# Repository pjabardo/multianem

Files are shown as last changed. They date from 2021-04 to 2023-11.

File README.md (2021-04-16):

# multianem - Multiple channel thermistor based CTA anemometer

This projecto has as its objective implement low cost multiple channel thermistor based constant temperature anemometer systems. This projecto includes the KICAD projects for the sensors and data acquisition system.

The main objective is to design a robust, cheap and easily sourced system. By easily sourced system, I mean that the components should be readily available in Brazil.

The project has different parts:

 * `multiname`: Basic board with 8 sensors.
 * `esp32-daq-board`: Data acquisition system for 32 channels
 * `multianem-box`: 3D printed/CNC casing for the system.
 * `multianemdaq`: embedded data acquisition software for the ESP32
 * Other software: data acquisition for Julia, R and Python (nothing to see yet...)

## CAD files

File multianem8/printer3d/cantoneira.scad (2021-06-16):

$fa = 1;
$fs = 0.4;

err = 0.0001;
esp = 3.0;
R = 1.5;

D = 9.5;

e = (D - 8.3)/2;
L = 190.0;
W = 190.0;
H = 80;
L1 = 12.0;



union(){
translate([-5, 0, 0])
rotate([0, -90, 0])
difference(){
union(){
    cube([esp, H, esp+L1]);
    cube([esp+L1, esp, esp+L1]);
    cube([esp+L1, H, esp]);
    
    translate([0, H-esp, 0])
    cube([esp+L1, esp, esp+L1]);
    
}

translate([esp+L1/2, esp+L1/2, -10])    
cylinder(h=20, r=1.5);

translate([esp+L1/2, H-esp-L1/2, -10])    
cylinder(h=20, r=1.5);

translate([esp+L1/2, -10, esp+L1/2])    
rotate([-90,0,0])
cylinder(h=20, r=1.5);

translate([esp+L1/2, H-10, esp+L1/2])    
rotate([-90,0,0])
cylinder(h=20, r=1.5);

translate([-10, esp+L1/2,  esp+L1/2])    
rotate([0, 90,0])
cylinder(h=20, r=1.5);

translate([-10, H-esp-L1/2,  esp+L1/2])    
rotate([0, 90,0])
cylinder(h=20, r=1.5);

}




difference(){
union(){
    cube([esp, H, esp+L1]);
    cube([esp+L1, esp, esp+L1]);
    cube([esp+L1, H, esp]);
    
    translate([0, H-esp, 0])
    cube([esp+L1, esp, esp+L1]);
    
}

translate([esp+L1/2, esp+L1/2, -10])    
cylinder(h=20, r=1.5);

translate([esp+L1/2, H-esp-L1/2, -10])    
cylinder(h=20, r=1.5);

translate([esp+L1/2, -10, esp+L1/2])    
rotate([-90,0,0])
cylinder(h=20, r=1.5);

translate([esp+L1/2, H-10, esp+L1/2])    
rotate([-90,0,0])
cylinder(h=20, r=1.5);

translate([-10, esp+L1/2,  esp+L1/2])    
rotate([0, 90,0])
cylinder(h=20, r=1.5);

translate([-10, H-esp-L1/2,  esp+L1/2])    
rotate([0, 90,0])
cylinder(h=20, r=1.5);

}


translate([-5, H+5, 0])
rotate([0, -90, 0])
difference(){
union(){
    cube([esp, H, esp+L1]);
    cube([esp+L1, esp, esp+L1]);
    cube([esp+L1, H, esp]);
    
    translate([0, H-esp, 0])
    cube([esp+L1, esp, esp+L1]);
    
}

translate([esp+L1/2, esp+L1/2, -10])    
cylinder(h=20, r=1.5);

translate([esp+L1/2, H-esp-L1/2, -10])    
cylinder(h=20, r=1.5);

translate([esp+L1/2, -10, esp+L1/2])    
rotate([-90,0,0])
cylinder(h=20, r=1.5);

translate([esp+L1/2, H-10, esp+L1/2])    
rotate([-90,0,0])
cylinder(h=20, r=1.5);

translate([-10, esp+L1/2,  esp+L1/2])    
rotate([0, 90,0])
cylinder(h=20, r=1.5);

translate([-10, H-esp-L1/2,  esp+L1/2])    
rotate([0, 90,0])
cylinder(h=20, r=1.5);

}


translate([0,H+5,0])
difference(){
union(){
    cube([esp, H, esp+L1]);
    cube([esp+L1, esp, esp+L1]);
    cube([esp+L1, H, esp]);
    
    translate([0, H-esp, 0])
    cube([esp+L1, esp, esp+L1]);
    
}

translate([esp+L1/2, esp+L1/2, -10])    
cylinder(h=20, r=1.5);

translate([esp+L1/2, H-esp-L1/2, -10])    
cylinder(h=20, r=1.5);

translate([esp+L1/2, -10, esp+L1/2])    
rotate([-90,0,0])
cylinder(h=20, r=1.5);

translate([esp+L1/2, H-10, esp+L1/2])    
rotate([-90,0,0])
cylinder(h=20, r=1.5);

translate([-10, esp+L1/2,  esp+L1/2])    
rotate([0, 90,0])
cylinder(h=20, r=1.5);

translate([-10, H-esp-L1/2,  esp+L1/2])    
rotate([0, 90,0])
cylinder(h=20, r=1.5);

}
}




// Nova conjunto
translate([40,0,0])
union(){
translate([-5, 0, 0])
rotate([0, -90, 0])
difference(){
union(){
    cube([esp, H, esp+L1]);
    cube([esp+L1, esp, esp+L1]);
    cube([esp+L1, H, esp]);
    
    translate([0, H-esp, 0])
    cube([esp+L1, esp, esp+L1]);
    
}

translate([esp+L1/2, esp+L1/2, -10])    
cylinder(h=20, r=1.5);

translate([esp+L1/2, H-esp-L1/2, -10])    
cylinder(h=20, r=1.5);

translate([esp+L1/2, -10, esp+L1/2])    
rotate([-90,0,0])
cylinder(h=20, r=1.5);

translate([esp+L1/2, H-10, esp+L1/2])    
rotate([-90,0,0])
cylinder(h=20, r=1.5);

translate([-10, esp+L1/2,  esp+L1/2])    
rotate([0, 90,0])
cylinder(h=20, r=1.5);

translate([-10, H-esp-L1/2,  esp+L1/2])    
rotate([0, 90,0])
cylinder(h=20, r=1.5);

}




difference(){
union(){
    cube([esp, H, esp+L1]);
    cube([esp+L1, esp, esp+L1]);
    cube([esp+L1, H, esp]);
    
    translate([0, H-esp, 0])
    cube([esp+L1, esp, esp+L1]);
    
}

translate([esp+L1/2, esp+L1/2, -10])    
cylinder(h=20, r=1.5);

translate([esp+L1/2, H-esp-L1/2, -10])    
cylinder(h=20, r=1.5);

translate([esp+L1/2, -10, esp+L1/2])    
rotate([-90,0,0])
cylinder(h=20, r=1.5);

translate([esp+L1/2, H-10, esp+L1/2])    
rotate([-90,0,0])
cylinder(h=20, r=1.5);

translate([-10, esp+L1/2,  esp+L1/2])    
rotate([0, 90,0])
cylinder(h=20, r=1.5);

translate([-10, H-esp-L1/2,  esp+L1/2])    
rotate([0, 90,0])
cylinder(h=20, r=1.5);

}


translate([-5, H+5, 0])
rotate([0, -90, 0])
difference(){
union(){
    cube([esp, H, esp+L1]);
    cube([esp+L1, esp, esp+L1]);
    cube([esp+L1, H, esp]);
    
    translate([0, H-esp, 0])
    cube([esp+L1, esp, esp+L1]);
    
}

translate([esp+L1/2, esp+L1/2, -10])    
cylinder(h=20, r=1.5);

translate([esp+L1/2, H-esp-L1/2, -10])    
cylinder(h=20, r=1.5);

translate([esp+L1/2, -10, esp+L1/2])    
rotate([-90,0,0])
cylinder(h=20, r=1.5);

translate([esp+L1/2, H-10, esp+L1/2])    
rotate([-90,0,0])
cylinder(h=20, r=1.5);

translate([-10, esp+L1/2,  esp+L1/2])    
rotate([0, 90,0])
cylinder(h=20, r=1.5);

translate([-10, H-esp-L1/2,  esp+L1/2])    
rotate([0, 90,0])
cylinder(h=20, r=1.5);

}


translate([0,H+5,0])
difference(){
union(){
    cube([esp, H, esp+L1]);
    cube([esp+L1, esp, esp+L1]);
    cube([esp+L1, H, esp]);
    
    translate([0, H-esp, 0])
    cube([esp+L1, esp, esp+L1]);
    
}

translate([esp+L1/2, esp+L1/2, -10])    
cylinder(h=20, r=1.5);

translate([esp+L1/2, H-esp-L1/2, -10])    
cylinder(h=20, r=1.5);

translate([esp+L1/2, -10, esp+L1/2])    
rotate([-90,0,0])
cylinder(h=20, r=1.5);

translate([esp+L1/2, H-10, esp+L1/2])    
rotate([-90,0,0])
cylinder(h=20, r=1.5);

translate([-10, esp+L1/2,  esp+L1/2])    
rotate([0, 90,0])
cylinder(h=20, r=1.5);

translate([-10, H-esp-L1/2,  esp+L1/2])    
rotate([0, 90,0])
cylinder(h=20, r=1.5);

}
}



// Nova conjunto
translate([80,0,0])
union(){
translate([-5, 0, 0])
rotate([0, -90, 0])
difference(){
union(){
    cube([esp, H, esp+L1]);
    cube([esp+L1, esp, esp+L1]);
    cube([esp+L1, H, esp]);
    
    translate([0, H-esp, 0])
    cube([esp+L1, esp, esp+L1]);
    
}

translate([esp+L1/2, esp+L1/2, -10])    
cylinder(h=20, r=1.5);

translate([esp+L1/2, H-esp-L1/2, -10])    
cylinder(h=20, r=1.5);

translate([esp+L1/2, -10, esp+L1/2])    
rotate([-90,0,0])
cylinder(h=20, r=1.5);

translate([esp+L1/2, H-10, esp+L1/2])    
rotate([-90,0,0])
cylinder(h=20, r=1.5);

translate([-10, esp+L1/2,  esp+L1/2])    
rotate([0, 90,0])
cylinder(h=20, r=1.5);

translate([-10, H-esp-L1/2,  esp+L1/2])    
rotate([0, 90,0])
cylinder(h=20, r=1.5);

}




difference(){
union(){
    cube([esp, H, esp+L1]);
    cube([esp+L1, esp, esp+L1]);
    cube([esp+L1, H, esp]);
    
    translate([0, H-esp, 0])
    cube([esp+L1, esp, esp+L1]);
    
}

translate([esp+L1/2, esp+L1/2, -10])    
cylinder(h=20, r=1.5);

translate([esp+L1/2, H-esp-L1/2, -10])    
cylinder(h=20, r=1.5);

translate([esp+L1/2, -10, esp+L1/2])    
rotate([-90,0,0])
cylinder(h=20, r=1.5);

translate([esp+L1/2, H-10, esp+L1/2])    
rotate([-90,0,0])
cylinder(h=20, r=1.5);

translate([-10, esp+L1/2,  esp+L1/2])    
rotate([0, 90,0])
cylinder(h=20, r=1.5);

translate([-10, H-esp-L1/2,  esp+L1/2])    
rotate([0, 90,0])
cylinder(h=20, r=1.5);

}


translate([-5, H+5, 0])
rotate([0, -90, 0])
difference(){
union(){
    cube([esp, H, esp+L1]);
    cube([esp+L1, esp, esp+L1]);
    cube([esp+L1, H, esp]);
    
    translate([0, H-esp, 0])
    cube([esp+L1, esp, esp+L1]);
    
}

translate([esp+L1/2, esp+L1/2, -10])    
cylinder(h=20, r=1.5);

translate([esp+L1/2, H-esp-L1/2, -10])    
cylinder(h=20, r=1.5);

translate([esp+L1/2, -10, esp+L1/2])    
rotate([-90,0,0])
cylinder(h=20, r=1.5);

translate([esp+L1/2, H-10, esp+L1/2])    
rotate([-90,0,0])
cylinder(h=20, r=1.5);

translate([-10, esp+L1/2,  esp+L1/2])    
rotate([0, 90,0])
cylinder(h=20, r=1.5);

translate([-10, H-esp-L1/2,  esp+L1/2])    
rotate([0, 90,0])
cylinder(h=20, r=1.5);

}


translate([0,H+5,0])
difference(){
union(){
    cube([esp, H, esp+L1]);
    cube([esp+L1, esp, esp+L1]);
    cube([esp+L1, H, esp]);
    
    translate([0, H-esp, 0])
    cube([esp+L1, esp, esp+L1]);
    
}

translate([esp+L1/2, esp+L1/2, -10])    
cylinder(h=20, r=1.5);

translate([esp+L1/2, H-esp-L1/2, -10])    
cylinder(h=20, r=1.5);

translate([esp+L1/2, -10, esp+L1/2])    
rotate([-90,0,0])
cylinder(h=20, r=1.5);

translate([esp+L1/2, H-10, esp+L1/2])    
rotate([-90,0,0])
cylinder(h=20, r=1.5);

translate([-10, esp+L1/2,  esp+L1/2])    
rotate([0, 90,0])
cylinder(h=20, r=1.5);

translate([-10, H-esp-L1/2,  esp+L1/2])    
rotate([0, 90,0])
cylinder(h=20, r=1.5);

}
}





// Nova conjunto
translate([120,0,0])
union(){
translate([-5, 0, 0])
rotate([0, -90, 0])
difference(){
union(){
    cube([esp, H, esp+L1]);
    cube([esp+L1, esp, esp+L1]);
    cube([esp+L1, H, esp]);
    
    translate([0, H-esp, 0])
    cube([esp+L1, esp, esp+L1]);
    
}

translate([esp+L1/2, esp+L1/2, -10])    
cylinder(h=20, r=1.5);

translate([esp+L1/2, H-esp-L1/2, -10])    
cylinder(h=20, r=1.5);

translate([esp+L1/2, -10, esp+L1/2])    
rotate([-90,0,0])
cylinder(h=20, r=1.5);
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

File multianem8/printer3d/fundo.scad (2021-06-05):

$fa = 1;
$fs = 0.4;

err = 0.0001;
esp = 2.0;

d = 3.0;
L = 190.0;
W = 190.0;
L1 = 12.0;

// Dimensões da placa
Wb = 148.59;
Lb = 165.1;

gapy = (190-148.59) /2;

union(){
    difference(){
        translate([0,0,-esp+err])
        cube([L, W, esp]);
    
        translate([6, gapy+5.08, -10])
        cylinder(h=20, r=1.5);
        
        translate([6, gapy+Wb-5.08, -10])
        cylinder(h=20, r=1.5);

        translate([6+Lb-2*5.08, gapy+5.08, -10])
        cylinder(h=20, r=1.5);
           
        translate([6+Lb-2*5.08, gapy+Wb-5.08, -10])
        cylinder(h=20, r=1.5);
        
     }

    difference(){
       union(){
            cube([esp, L1+esp, L1]);
            cube([L1+esp, esp, L1]);
        }
     translate([L1+esp-6,-10, L1/2]) 
     rotate([-90,0,0])
     cylinder(h=20, r=1.5);

     translate([-10,L1+esp-6, L1/2]) 
     rotate([0,90,0])
     cylinder(h=20, r=1.5);
     
    }

translate([0,190,0])
rotate([0,0,-90])
    difference(){
       union(){
            cube([esp, L1+esp, L1]);
            cube([L1+esp, esp, L1]);
        }
     translate([L1+esp-6,-10, L1/2]) 
     rotate([-90,0,0])
     cylinder(h=20, r=1.5);

     translate([-10,L1+esp-6, L1/2]) 
     rotate([0,90,0])
     cylinder(h=20, r=1.5);
     
    }
    
translate([190,0,0])
rotate([0,0,90])
    difference(){
       union(){
            cube([esp, L1+esp, L1]);
            cube([L1+esp, esp, L1]);
        }
     translate([L1+esp-6,-10, L1/2]) 
     rotate([-90,0,0])
     cylinder(h=20, r=1.5);

     translate([-10,L1+esp-6, L1/2]) 
     rotate([0,90,0])
     cylinder(h=20, r=1.5);
     
    }
    
    
translate([190,190,0])
rotate([0,0,-180])
    difference(){
       union(){
            cube([esp, L1+esp, L1]);
            cube([L1+esp, esp, L1]);
        }
     translate([L1+esp-6,-10, L1/2]) 
     rotate([-90,0,0])
     cylinder(h=20, r=1.5);

     translate([-10,L1+esp-6, L1/2]) 
     rotate([0,90,0])
     cylinder(h=20, r=1.5);
     
    }
    
}

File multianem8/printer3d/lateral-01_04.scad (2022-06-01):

$fa = 1;
$fs = 0.4;

err = 0.0001;
esp = 2.0;
R = 1.5;

D = 9.5;

e = (D - 8.3)/2;
L = 190.0;
W = 190.0;
H = 70;
L1 = 12.0;
fh = 0.6;

union(){
difference(){
    cube([W, H, esp]);
    
    translate([esp+L1/2, esp+L1/2,-10])
    cylinder(h=20, r=1.5);

    translate([W - esp-L1/2, esp+L1/2,-10])
    cylinder(h=20, r=1.5);

    translate([esp+L1/2, H-esp-L1/2,-10])
    cylinder(h=20, r=1.5);

    translate([W-esp-L1/2, H-esp-L1/2,-10])
    cylinder(h=20, r=1.5);



    translate([50,H*fh, -10])
    difference(){
        cylinder(h=20, r=D/2);

        translate([D/2-e, -D/2, -10])
        cube([D,D,40]);

        translate([-1.5*D+e, -D/2, -10])
        cube([D,D,40]);
    }

    translate([80,H*fh, -10])
    difference(){
        cylinder(h=20, r=D/2);

        translate([D/2-e, -D/2, -10])
        cube([D,D,40]);

        translate([-1.5*D+e, -D/2, -10])
        cube([D,D,40]);
    }

    translate([110,H*fh, -10])
    difference(){
        cylinder(h=20, r=D/2);

        translate([D/2-e, -D/2, -10])
        cube([D,D,40]);

        translate([-1.5*D+e, -D/2, -10])
        cube([D,D,40]);
    }

    translate([140,H*fh, -10])
    difference(){
        cylinder(h=20, r=D/2);

        translate([D/2-e, -D/2, -10])
        cube([D,D,40]);

        translate([-1.5*D+e, -D/2, -10])
        cube([D,D,40]);
    }
    
  //   translate([30, 55,-10])   
  //  cube([130,10,20]);


}
translate([50-D/3,H*fh-2*D, 0])
linear_extrude(1.6*esp)
    text("1");

translate([80-D/3,H*fh-2*D, 0])
linear_extrude(1.6*esp)
    text("2");

translate([110-D/3,H*fh-2*D, 0])
linear_extrude(1.6*esp)
    text("3");

translate([140-D/3,H*fh-2*D, 0])
linear_extrude(1.6*esp)
    text("4");

}

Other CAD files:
multianem8/printer3d/lateral-05_08.scad
multianem8/printer3d/lateral.scad

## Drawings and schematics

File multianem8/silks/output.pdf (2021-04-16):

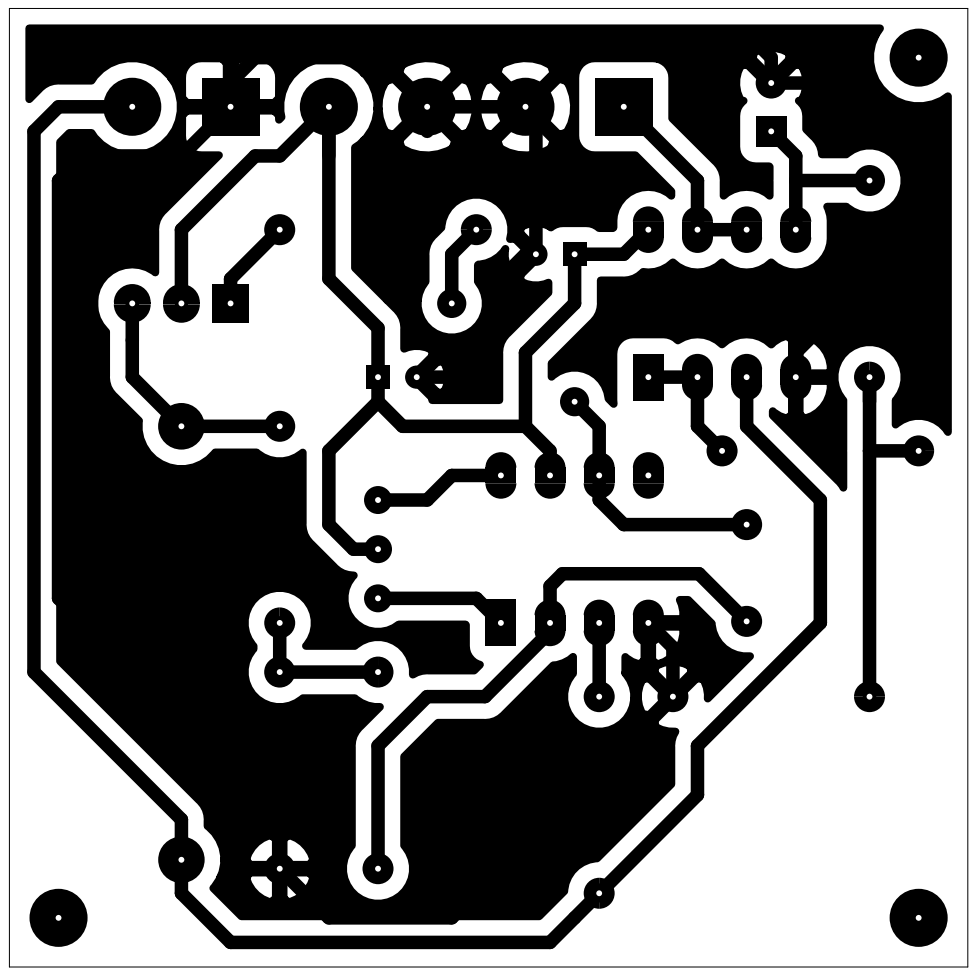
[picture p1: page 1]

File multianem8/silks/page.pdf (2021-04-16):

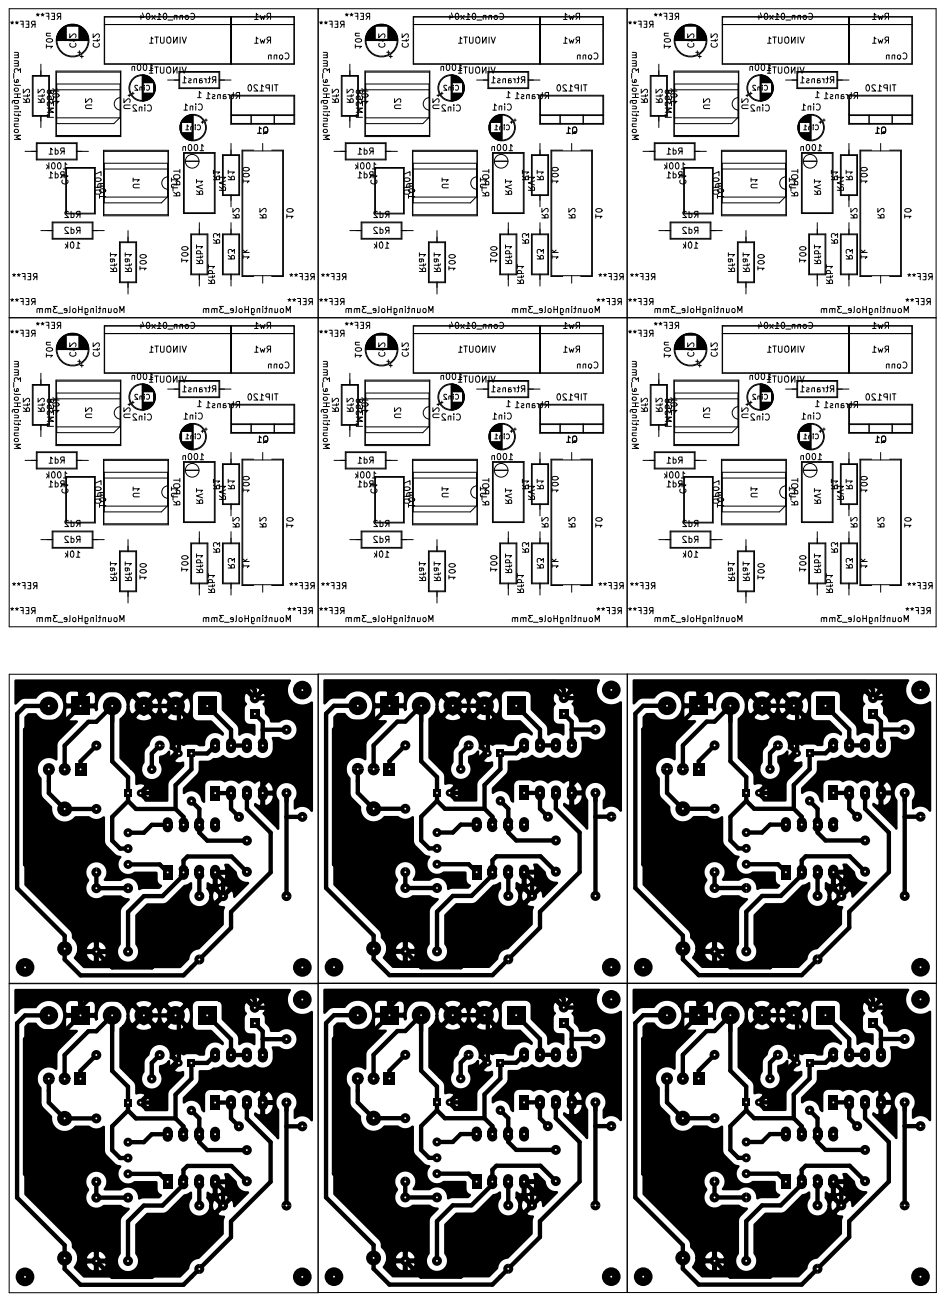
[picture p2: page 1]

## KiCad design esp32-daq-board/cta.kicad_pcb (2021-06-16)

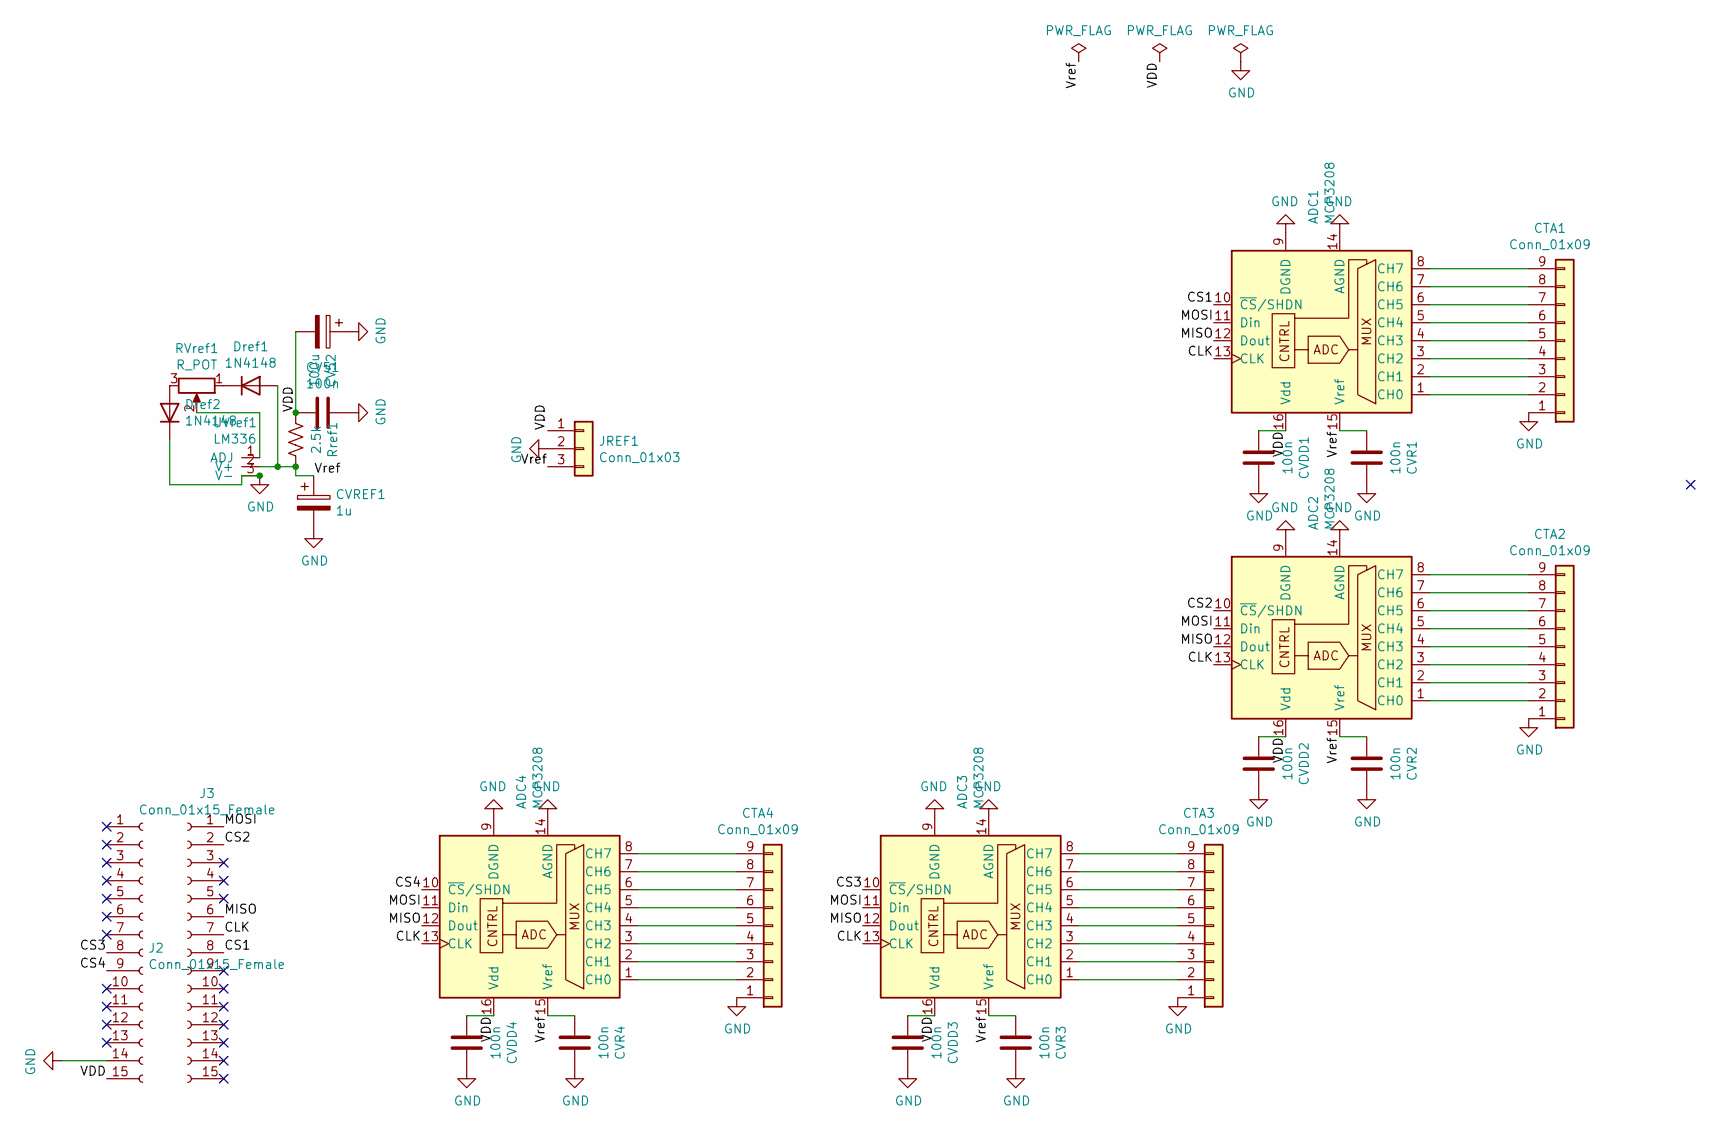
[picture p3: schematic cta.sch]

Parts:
ADC1, ADC2, ADC3, ADC4: MCP3208; DIP-16_W7.62mm_LongPads
CTA1, CTA2, CTA3, CTA4: Conn_01x09; PinHeader_1x09_P2.54mm_Vertical
CV51: 100n; C_Rect_L7.2mm_W3.0mm_P5.00mm_FKS2_FKP2_MKS2_MKP2
CV52: 100u; CP_Radial_D6.3mm_P2.50mm
CVDD1, CVDD2, CVDD3, CVDD4: 100n; C_Rect_L7.2mm_W3.0mm_P5.00mm_FKS2_FKP2_MKS2_MKP2
CVR1, CVR2, CVR3, CVR4: 100n; C_Rect_L7.2mm_W3.0mm_P5.00mm_FKS2_FKP2_MKS2_MKP2
CVREF1: 1u; CP_Radial_D4.0mm_P2.00mm
Dref1, Dref2: 1N4148; D_DO-35_SOD27_P7.62mm_Horizontal
J2, J3: Conn_01x15_Female; PinSocket_1x15_P2.54mm_Vertical
JREF1: Conn_01x03; TerminalBlock_bornier-3_P5.08mm
RVref1: R_POT; Potentiometer_Bourns_3296W_Vertical
Rref1: 2.5k; R_Axial_DIN0207_L6.3mm_D2.5mm_P10.16mm_Horizontal
UVref1: LM336; TO-92L_Inline_Wide

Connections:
/CLK: ADC1.13 (CLK), ADC2.13 (CLK), ADC3.13 (CLK), ADC4.13 (CLK), J3.7
/CS1: ADC1.10 (~CS~/SHDN), J3.8
/CS2: ADC2.10 (~CS~/SHDN), J3.2
/CS3: ADC3.10 (~CS~/SHDN), J2.8
/CS4: ADC4.10 (~CS~/SHDN), J2.9
/MISO: ADC1.12 (Dout), ADC2.12 (Dout), ADC3.12 (Dout), ADC4.12 (Dout), J3.6
/MOSI: ADC1.11 (Din), ADC2.11 (Din), ADC3.11 (Din), ADC4.11 (Din), J3.1
/VDD: ADC1.16 (Vdd), ADC2.16 (Vdd), ADC3.16 (Vdd), ADC4.16 (Vdd), CV51.2, CV52.2, CVDD1.2, CVDD2.2, CVDD3.2, CVDD4.2, J2.15, JREF1.1, Rref1.2
/Vref: ADC1.15 (Vref), ADC2.15 (Vref), ADC3.15 (Vref), ADC4.15 (Vref), CVR1.2, CVR2.2, CVR3.2, CVR4.2, CVREF1.1, Dref1.2 (A), JREF1.3, Rref1.1, UVref1.2 (V+)
GND: ADC1.9 (DGND), ADC1.14 (AGND), ADC2.9 (DGND), ADC2.14 (AGND), ADC3.9 (DGND), ADC3.14 (AGND), ADC4.9 (DGND), ADC4.14 (AGND), CTA1.1, CTA2.1, CTA3.1, CTA4.1, CV51.1, CV52.1, CVDD1.1, CVDD2.1, CVDD3.1, CVDD4.1, CVR1.1, CVR2.1, CVR3.1, CVR4.1, CVREF1.2, Dref2.1 (K), J2.14, JREF1.2, UVref1.3 (V-)
unnamed: ADC1.1 (CH0), CTA1.2
unnamed: ADC1.2 (CH1), CTA1.3
unnamed: ADC1.3 (CH2), CTA1.4
unnamed: ADC1.4 (CH3), CTA1.5
unnamed: ADC1.5 (CH4), CTA1.6
unnamed: ADC1.6 (CH5), CTA1.7
unnamed: ADC1.7 (CH6), CTA1.8
unnamed: ADC1.8 (CH7), CTA1.9
unnamed: ADC2.1 (CH0), CTA2.2
unnamed: ADC2.2 (CH1), CTA2.3
unnamed: ADC2.3 (CH2), CTA2.4
unnamed: ADC2.4 (CH3), CTA2.5
unnamed: ADC2.5 (CH4), CTA2.6
unnamed: ADC2.6 (CH5), CTA2.7
unnamed: ADC2.7 (CH6), CTA2.8
unnamed: ADC2.8 (CH7), CTA2.9
unnamed: ADC3.1 (CH0), CTA3.2
unnamed: ADC3.2 (CH1), CTA3.3
unnamed: ADC3.3 (CH2), CTA3.4
unnamed: ADC3.4 (CH3), CTA3.5
unnamed: ADC3.5 (CH4), CTA3.6
unnamed: ADC3.6 (CH5), CTA3.7
unnamed: ADC3.7 (CH6), CTA3.8
unnamed: ADC3.8 (CH7), CTA3.9
unnamed: ADC4.1 (CH0), CTA4.2
unnamed: ADC4.2 (CH1), CTA4.3
unnamed: ADC4.3 (CH2), CTA4.4
unnamed: ADC4.4 (CH3), CTA4.5
unnamed: ADC4.5 (CH4), CTA4.6
unnamed: ADC4.6 (CH5), CTA4.7
unnamed: ADC4.7 (CH6), CTA4.8
unnamed: ADC4.8 (CH7), CTA4.9
unnamed: Dref1.1 (K), RVref1.1
unnamed: Dref2.2 (A), RVref1.3
unnamed: RVref1.2, UVref1.1 (ADJ)

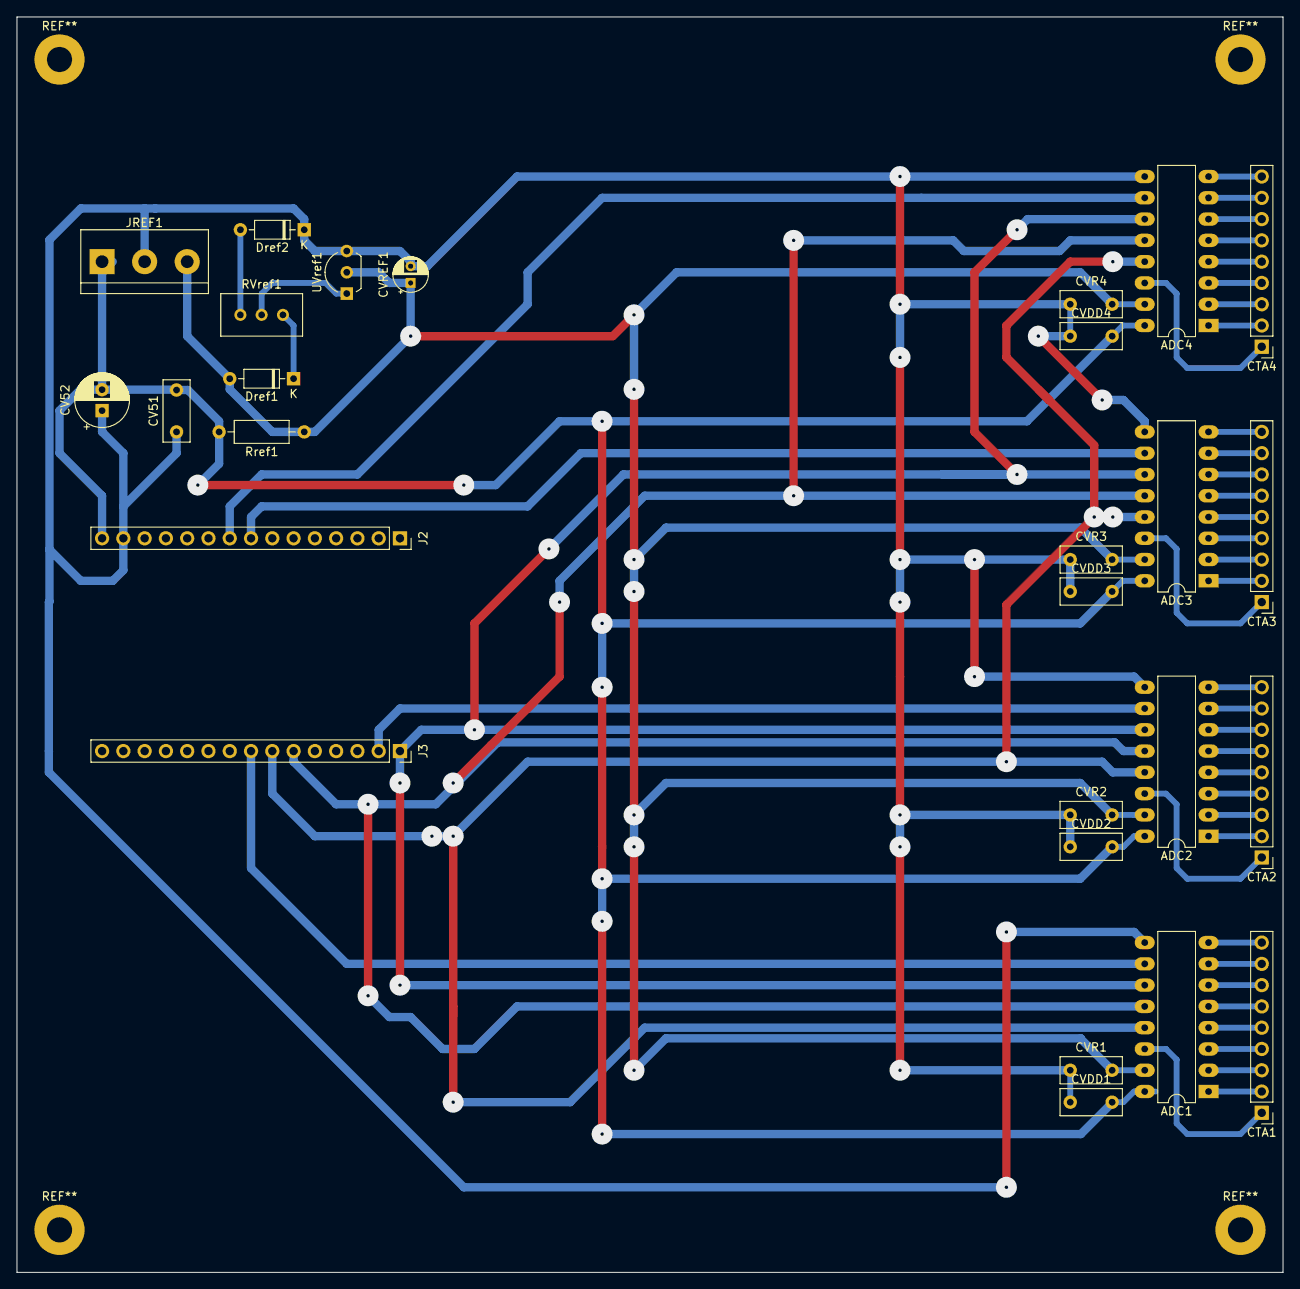
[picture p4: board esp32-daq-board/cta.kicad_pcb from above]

Board: 2 copper layers, 151.1 x 149.9 mm, 27 parts (0 on the bottom side), 45 nets.

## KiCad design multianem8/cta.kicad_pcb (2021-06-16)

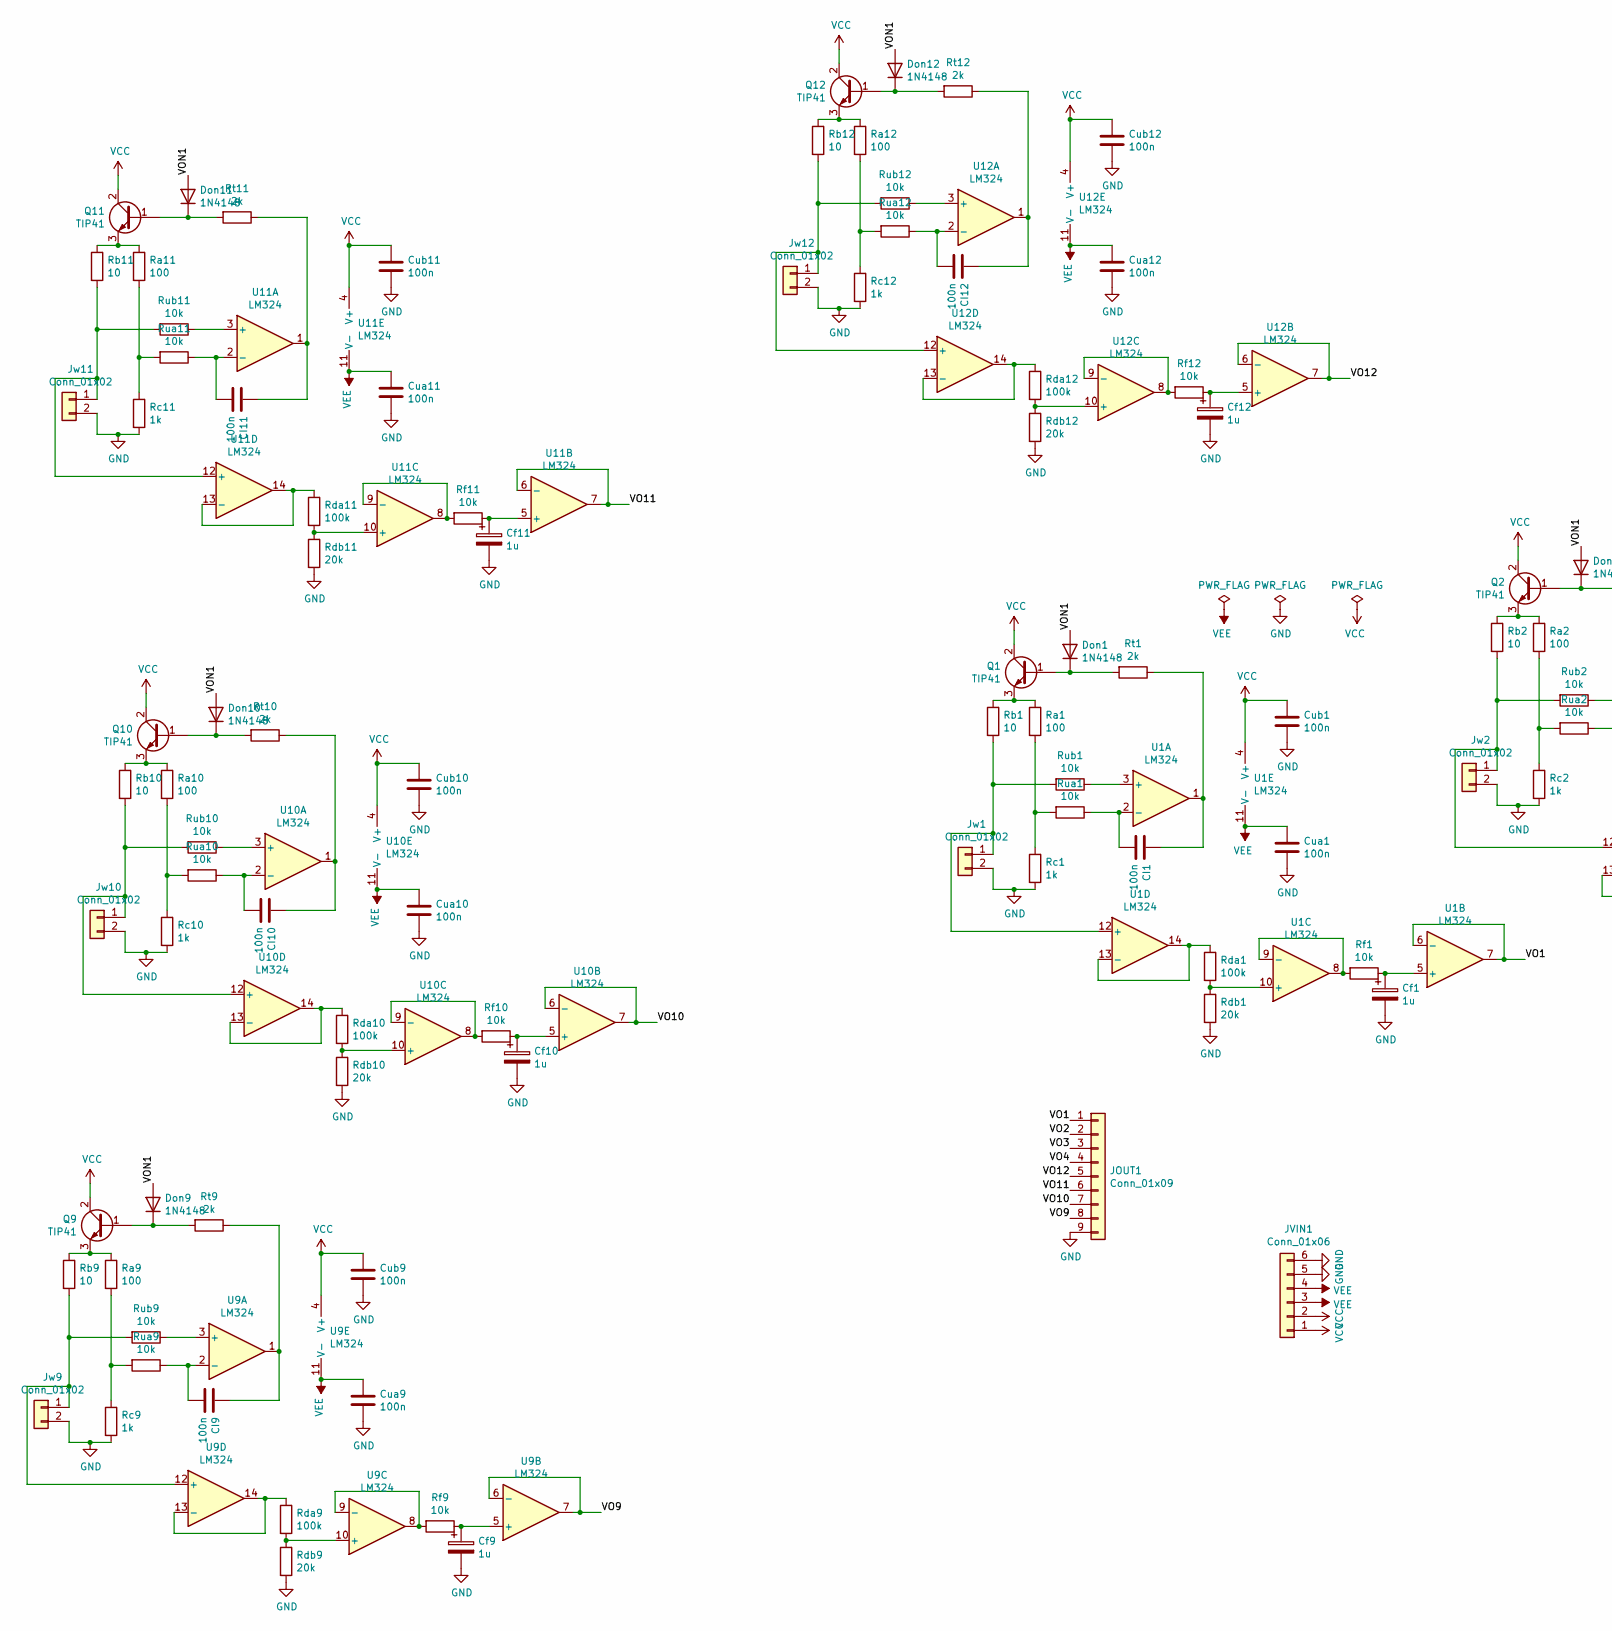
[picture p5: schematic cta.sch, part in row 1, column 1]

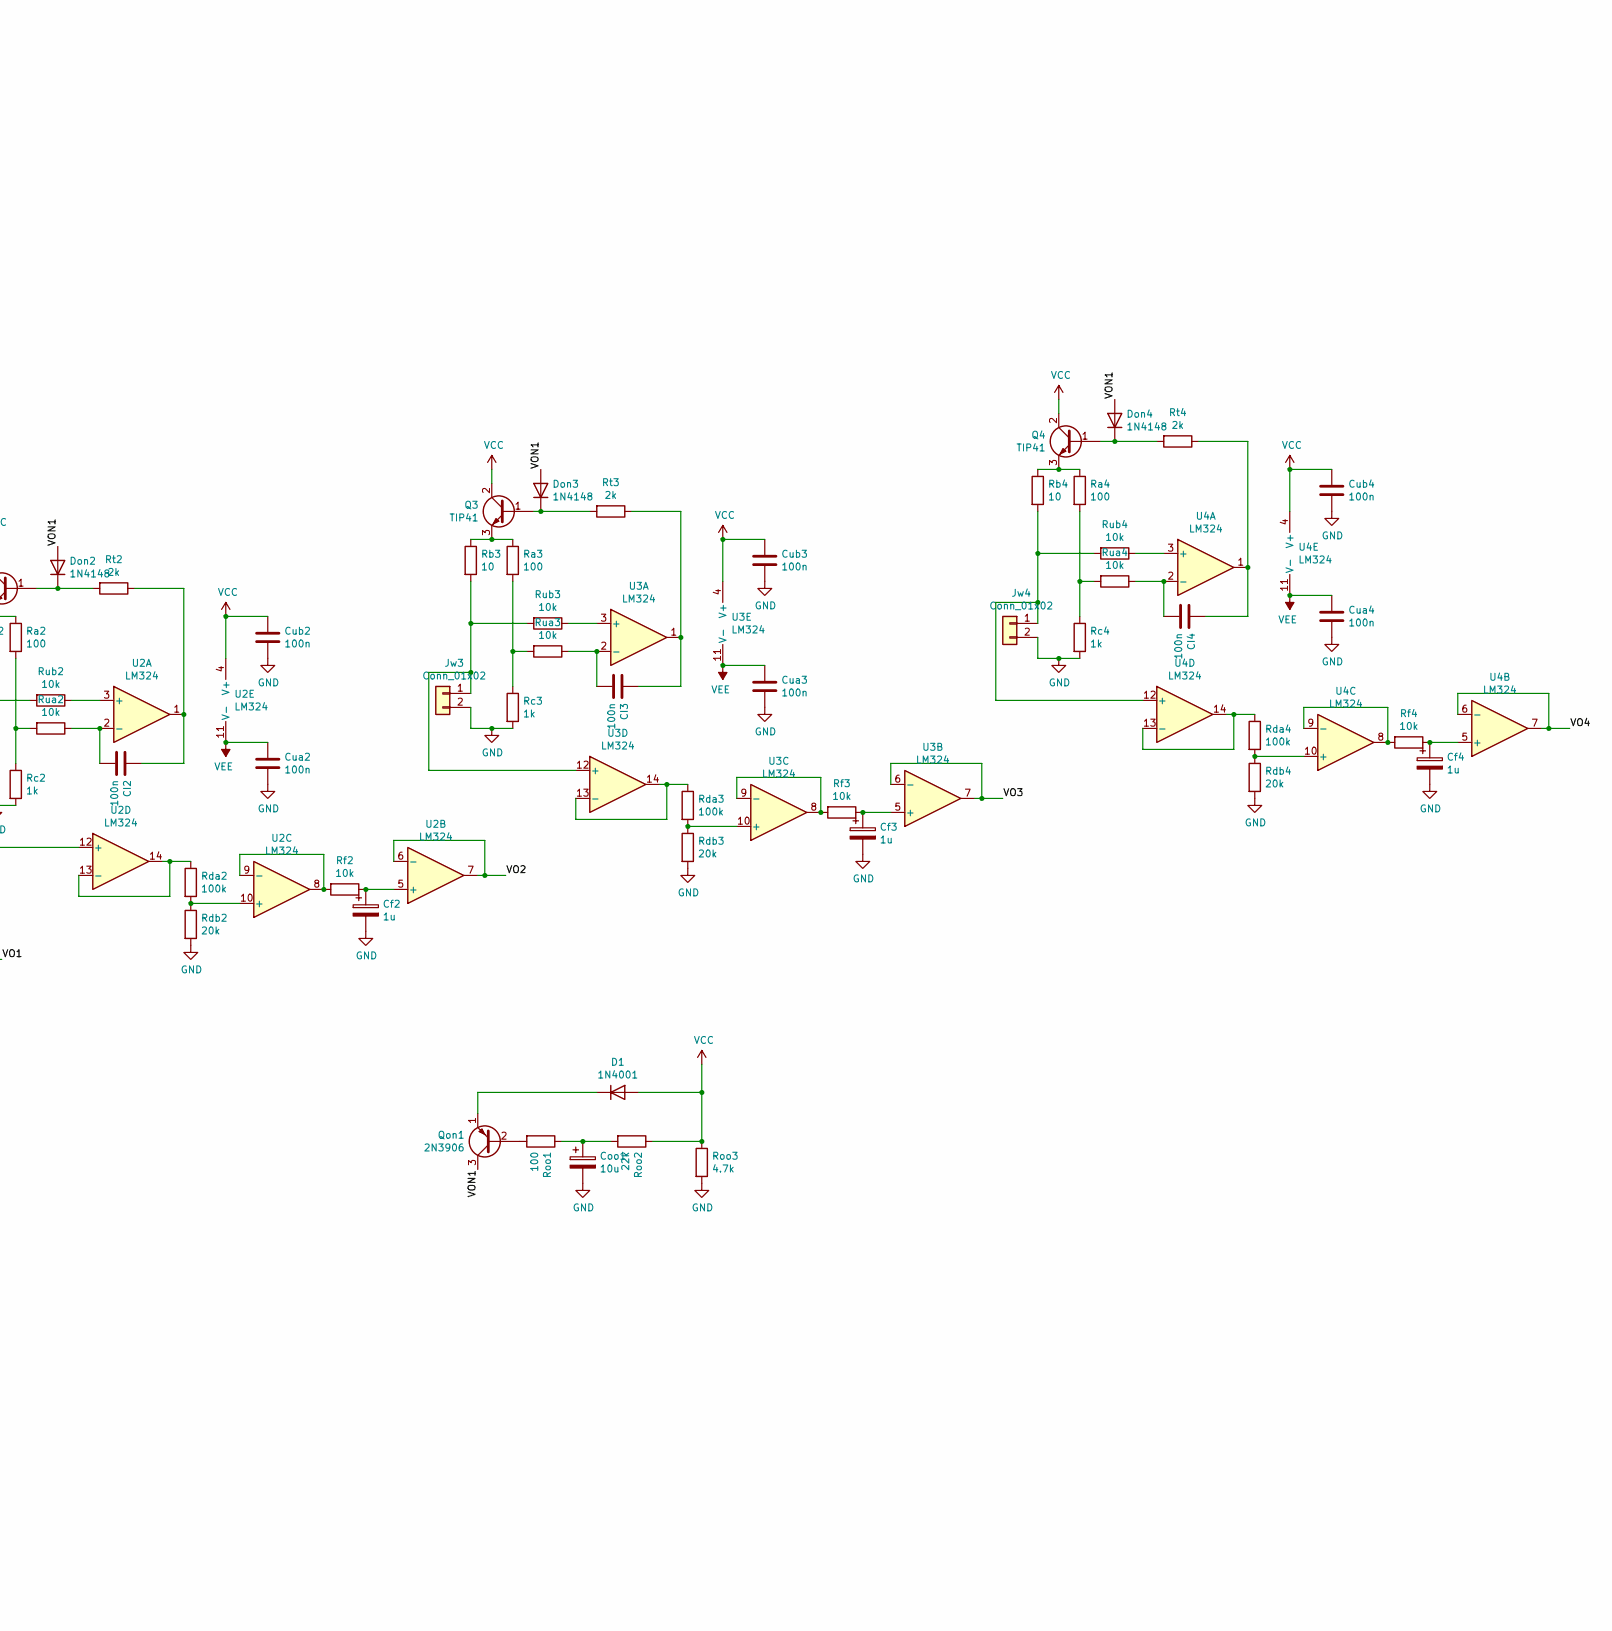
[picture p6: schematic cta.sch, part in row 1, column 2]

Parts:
CI1, CI2, CI3, CI4, CI9, CI10, CI11, CI12: 100n; C_Rect_L7.2mm_W3.5mm_P5.00mm_FKS2_FKP2_MKS2_MKP2
Cf1, Cf2, Cf3, Cf4, Cf9, Cf10, Cf11, Cf12: 1u; CP_Radial_D5.0mm_P2.50mm
Coo1: 10u; CP_Radial_D5.0mm_P2.50mm
Cua1, Cua2, Cua3, Cua4, Cua9, Cua10, Cua11, Cua12: 100n; C_Disc_D5.0mm_W2.5mm_P2.50mm
Cub1, Cub2, Cub3, Cub4, Cub9, Cub10, Cub11, Cub12: 100n; C_Disc_D5.0mm_W2.5mm_P2.50mm
D1: 1N4001; D_DO-41_SOD81_P10.16mm_Horizontal
Don1, Don2, Don3, Don4, Don9, Don10, Don11, Don12: 1N4148; D_DO-35_SOD27_P7.62mm_Horizontal
JOUT1: Conn_01x09; PinHeader_1x09_P2.54mm_Vertical
JVIN1: Conn_01x06; TerminalBlock_bornier-6_P5.08mm
Jw1, Jw2, Jw3, Jw4, Jw9, Jw10, Jw11, Jw12: Conn_01x02; PinHeader_1x02_P2.54mm_Vertical
Q1, Q2, Q3, Q4, Q9, Q10, Q11, Q12: TIP41; TO-220-3_Vertical
Qon1: 2N3906; TO-92_Inline_Wide
Ra1, Ra2, Ra3, Ra4, Ra9, Ra10, Ra11, Ra12: 100; R_Axial_DIN0207_L6.3mm_D2.5mm_P10.16mm_Horizontal
Rb1, Rb2, Rb3, Rb4, Rb9, Rb10, Rb11, Rb12: 10; R_Axial_DIN0414_L11.9mm_D4.5mm_P15.24mm_Horizontal
Rc1, Rc2, Rc3, Rc4, Rc9, Rc10, Rc11, Rc12: 1k; R_Axial_DIN0207_L6.3mm_D2.5mm_P10.16mm_Horizontal
Rda1, Rda2, Rda3, Rda4, Rda9, Rda10, Rda11, Rda12: 100k; R_Axial_DIN0207_L6.3mm_D2.5mm_P10.16mm_Horizontal
Rdb1, Rdb2, Rdb3, Rdb4, Rdb9, Rdb10, Rdb11, Rdb12: 20k; R_Axial_DIN0207_L6.3mm_D2.5mm_P10.16mm_Horizontal
Rf1, Rf2, Rf3, Rf4, Rf9, Rf10, Rf11, Rf12: 10k; R_Axial_DIN0207_L6.3mm_D2.5mm_P10.16mm_Horizontal
Roo1: 100; R_Axial_DIN0207_L6.3mm_D2.5mm_P10.16mm_Horizontal
Roo2: 22k; R_Axial_DIN0207_L6.3mm_D2.5mm_P10.16mm_Horizontal
Roo3: 4.7k; R_Axial_DIN0207_L6.3mm_D2.5mm_P10.16mm_Horizontal
Rt1, Rt2, Rt3, Rt4, Rt9, Rt10, Rt11, Rt12: 2k; R_Axial_DIN0207_L6.3mm_D2.5mm_P10.16mm_Horizontal
Rua1, Rua2, Rua3, Rua4, Rua9, Rua10, Rua11, Rua12: 10k; R_Axial_DIN0207_L6.3mm_D2.5mm_P10.16mm_Horizontal
Rub1, Rub2, Rub3, Rub4, Rub9, Rub10, Rub11, Rub12: 10k; R_Axial_DIN0207_L6.3mm_D2.5mm_P10.16mm_Horizontal
U1, U2, U3, U4, U9, U10, U11, U12: LM324; DIP-14_W7.62mm_LongPads

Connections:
/VO1: JOUT1.1, U1.6 (-), U1.7
/VO2: JOUT1.2, U2.6 (-), U2.7
/VO3: JOUT1.3, U3.6 (-), U3.7
/VO4: JOUT1.4, U4.6 (-), U4.7
/VO9: JOUT1.8, U9.6 (-), U9.7
/VO10: JOUT1.7, U10.6 (-), U10.7
/VO11: JOUT1.6, U11.6 (-), U11.7
/VO12: JOUT1.5, U12.6 (-), U12.7
/VON1: Don1.2 (A), Don2.2 (A), Don3.2 (A), Don4.2 (A), Don9.2 (A), Don10.2 (A), Don11.2 (A), Don12.2 (A), Qon1.3 (C)
GND: Cf1.2, Cf2.2, Cf3.2, Cf4.2, Cf9.2, Cf10.2, Cf11.2, Cf12.2, Coo1.2, Cua1.2, Cua2.2, Cua3.2, Cua4.2, Cua9.2, Cua10.2, Cua11.2, Cua12.2, Cub1.2, Cub2.2, Cub3.2, Cub4.2, Cub9.2, Cub10.2, Cub11.2, Cub12.2, JOUT1.9, JVIN1.5, JVIN1.6, Jw1.2, Jw2.2, Jw3.2, Jw4.2, Jw9.2, Jw10.2, Jw11.2, Jw12.2, Rc1.2, Rc2.2, Rc3.2, Rc4.2, Rc9.2, Rc10.2, Rc11.2, Rc12.2, Rdb1.2, Rdb2.2, Rdb3.2, Rdb4.2, Rdb9.2, Rdb10.2, Rdb11.2, Rdb12.2, Roo3.2
unnamed: CI1.1, Rt1.1, U1.1
unnamed: CI1.2, Rua1.1, U1.2 (-)
unnamed: CI2.1, Rt2.1, U2.1
unnamed: CI2.2, Rua2.1, U2.2 (-)
unnamed: CI3.1, Rt3.1, U3.1
unnamed: CI3.2, Rua3.1, U3.2 (-)
unnamed: CI4.1, Rt4.1, U4.1
unnamed: CI4.2, Rua4.1, U4.2 (-)
unnamed: CI9.1, Rt9.1, U9.1
unnamed: CI9.2, Rua9.1, U9.2 (-)
unnamed: CI10.1, Rt10.1, U10.1
unnamed: CI10.2, Rua10.1, U10.2 (-)
unnamed: CI11.1, Rt11.1, U11.1
unnamed: CI11.2, Rua11.1, U11.2 (-)
unnamed: CI12.1, Rt12.1, U12.1
unnamed: CI12.2, Rua12.1, U12.2 (-)
unnamed: Cf1.1, Rf1.1, U1.5 (+)
unnamed: Cf2.1, Rf2.1, U2.5 (+)
unnamed: Cf3.1, Rf3.1, U3.5 (+)
unnamed: Cf4.1, Rf4.1, U4.5 (+)
unnamed: Cf9.1, Rf9.1, U9.5 (+)
unnamed: Cf10.1, Rf10.1, U10.5 (+)
unnamed: Cf11.1, Rf11.1, U11.5 (+)
unnamed: Cf12.1, Rf12.1, U12.5 (+)
unnamed: Coo1.1, Roo1.1, Roo2.2
unnamed: D1.1 (K), Qon1.1 (E)
unnamed: Don1.1 (K), Q1.1 (B), Rt1.2
unnamed: Don2.1 (K), Q2.1 (B), Rt2.2
unnamed: Don3.1 (K), Q3.1 (B), Rt3.2
unnamed: Don4.1 (K), Q4.1 (B), Rt4.2
unnamed: Don9.1 (K), Q9.1 (B), Rt9.2
unnamed: Don10.1 (K), Q10.1 (B), Rt10.2
unnamed: Don11.1 (K), Q11.1 (B), Rt11.2
unnamed: Don12.1 (K), Q12.1 (B), Rt12.2
unnamed: Jw1.1, Rb1.2, Rub1.2, U1.12 (+)
unnamed: Jw2.1, Rb2.2, Rub2.2, U2.12 (+)
unnamed: Jw3.1, Rb3.2, Rub3.2, U3.12 (+)
unnamed: Jw4.1, Rb4.2, Rub4.2, U4.12 (+)
unnamed: Jw9.1, Rb9.2, Rub9.2, U9.12 (+)
unnamed: Jw10.1, Rb10.2, Rub10.2, U10.12 (+)
unnamed: Jw11.1, Rb11.2, Rub11.2, U11.12 (+)
unnamed: Jw12.1, Rb12.2, Rub12.2, U12.12 (+)
unnamed: Q1.3 (E), Ra1.1, Rb1.1
unnamed: Q2.3 (E), Ra2.1, Rb2.1
unnamed: Q3.3 (E), Ra3.1, Rb3.1
unnamed: Q4.3 (E), Ra4.1, Rb4.1
unnamed: Q9.3 (E), Ra9.1, Rb9.1
unnamed: Q10.3 (E), Ra10.1, Rb10.1
unnamed: Q11.3 (E), Ra11.1, Rb11.1
unnamed: Q12.3 (E), Ra12.1, Rb12.1
unnamed: Qon1.2 (B), Roo1.2
unnamed: Ra1.2, Rc1.1, Rua1.2
unnamed: Ra2.2, Rc2.1, Rua2.2
unnamed: Ra3.2, Rc3.1, Rua3.2
unnamed: Ra4.2, Rc4.1, Rua4.2
unnamed: Ra9.2, Rc9.1, Rua9.2
unnamed: Ra10.2, Rc10.1, Rua10.2
unnamed: Ra11.2, Rc11.1, Rua11.2
unnamed: Ra12.2, Rc12.1, Rua12.2
unnamed: Rda1.1, U1.13 (-), U1.14
unnamed: Rda1.2, Rdb1.1, U1.10 (+)
unnamed: Rda2.1, U2.13 (-), U2.14
unnamed: Rda2.2, Rdb2.1, U2.10 (+)
unnamed: Rda3.1, U3.13 (-), U3.14
unnamed: Rda3.2, Rdb3.1, U3.10 (+)
unnamed: Rda4.1, U4.13 (-), U4.14
unnamed: Rda4.2, Rdb4.1, U4.10 (+)
unnamed: Rda9.1, U9.13 (-), U9.14
unnamed: Rda9.2, Rdb9.1, U9.10 (+)
unnamed: Rda10.1, U10.13 (-), U10.14
unnamed: Rda10.2, Rdb10.1, U10.10 (+)
unnamed: Rda11.1, U11.13 (-), U11.14
unnamed: Rda11.2, Rdb11.1, U11.10 (+)
unnamed: Rda12.1, U12.13 (-), U12.14
unnamed: Rda12.2, Rdb12.1, U12.10 (+)
unnamed: Rf1.2, U1.8, U1.9 (-)
unnamed: Rf2.2, U2.8, U2.9 (-)
unnamed: Rf3.2, U3.8, U3.9 (-)
unnamed: Rf4.2, U4.8, U4.9 (-)
unnamed: Rf9.2, U9.8, U9.9 (-)
unnamed: Rf10.2, U10.8, U10.9 (-)
unnamed: Rf11.2, U11.8, U11.9 (-)
unnamed: Rf12.2, U12.8, U12.9 (-)
unnamed: Rub1.1, U1.3 (+)
unnamed: Rub2.1, U2.3 (+)
unnamed: Rub3.1, U3.3 (+)
unnamed: Rub4.1, U4.3 (+)
unnamed: Rub9.1, U9.3 (+)
unnamed: Rub10.1, U10.3 (+)
unnamed: Rub11.1, U11.3 (+)
unnamed: Rub12.1, U12.3 (+)
VCC: Cub1.1, Cub2.1, Cub3.1, Cub4.1, Cub9.1, Cub10.1, Cub11.1, Cub12.1, D1.2 (A), JVIN1.1, JVIN1.2, Q1.2 (C), Q2.2 (C), Q3.2 (C), Q4.2 (C), Q9.2 (C), Q10.2 (C), Q11.2 (C), Q12.2 (C), Roo2.1, Roo3.1, U1.4 (V+), U2.4 (V+), U3.4 (V+), U4.4 (V+), U9.4 (V+), U10.4 (V+), U11.4 (V+), U12.4 (V+)
VEE: Cua1.1, Cua2.1, Cua3.1, Cua4.1, Cua9.1, Cua10.1, Cua11.1, Cua12.1, JVIN1.3, JVIN1.4, U1.11 (V-), U2.11 (V-), U3.11 (V-), U4.11 (V-), U9.11 (V-), U10.11 (V-), U11.11 (V-), U12.11 (V-)

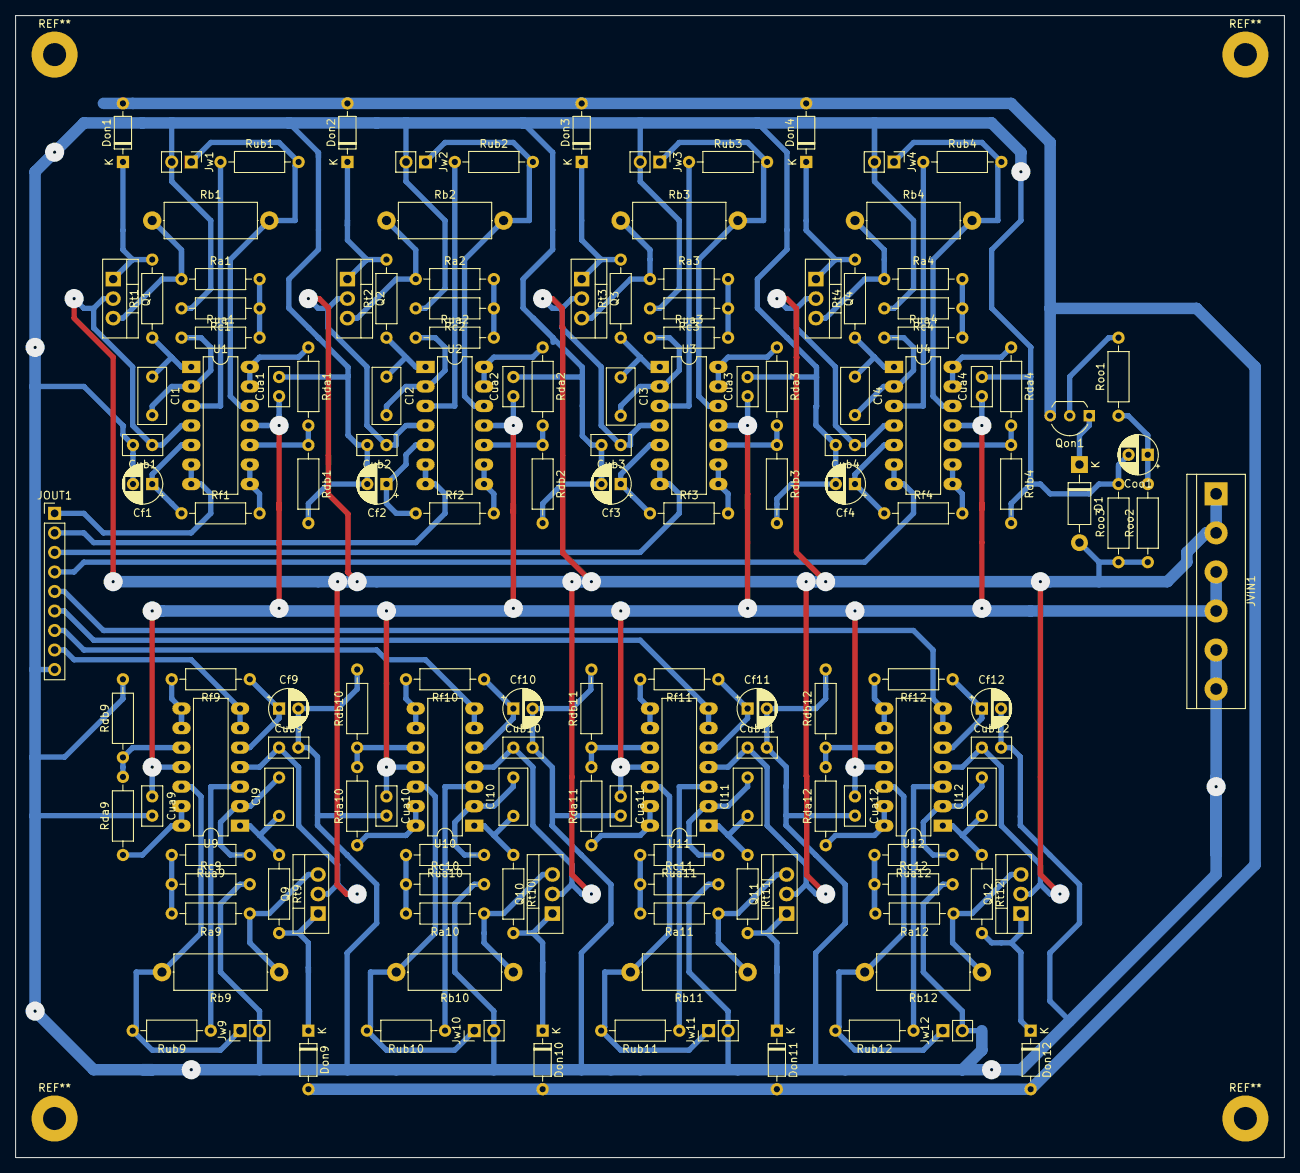
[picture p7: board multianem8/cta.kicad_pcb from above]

Board: 2 copper layers, 165.1 x 148.6 mm, 144 parts (0 on the bottom side), 103 nets.

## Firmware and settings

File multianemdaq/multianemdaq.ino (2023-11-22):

/**
 * Basic ADC reading example.
 * - connects to ADC
 * - reads value from channel
 * - converts value to analog voltage
 */

#include "espmcpdaq.h"

#define _USE_SERIAL_
//#define _USE_WIFI_

#define SPI_MOSI1   23       
#define SPI_MISO1   19
#define SPI_CLK1    18

#define SPI_CS1      5        // SPI slave select
#define SPI_CS2      22
#define SPI_CS3      25
#define SPI_CS4      26

//#define SPI_MOSI2   13       
//#define SPI_MISO2   12
//#define SPI_CLK2    14

#define ADC_VREF    2500     // 3.3V Vref
#define ADC_CLK     1600000  // SPI clock 1.6MHz

#define NCHANS 8
#define NMCP 4
#define TOTAL_CHANS 32

//const uint32_t HEAD = 0xff495054;  // 0x49 -> 'I', 0x50 -> 'P', 0x54 -> 'T'
//const uint32_t FOOT = 0xff00ff00;


SPIClass spi1(VSPI);

MCP3208 adc1(ADC_VREF, SPI_CS1, &spi1);
MCP3208 adc2(ADC_VREF, SPI_CS2, &spi1);
MCP3208 adc3(ADC_VREF, SPI_CS3, &spi1);
MCP3208 adc4(ADC_VREF, SPI_CS4, &spi1);


#ifdef _USE_SERIAL_
#undef _USE_WIFI_

ESPDaq<HardwareSerial> espdaq(&adc1, &adc2, &adc3, &adc4);

#endif

#ifdef _USE_WIFI_
#undef _USE_SERIAL_

#include<WiFi.h>
const char *ssid = "tunel";
const char *password = "gvento123";

WiFiServer server(9523);

ESPDaq<WiFiClient> espdaq(&adc1, &adc2, &adc3, &adc4);



void connect_wifi_ap(){
  uint8_t dcnt = 0;
  if (WiFi.status() != WL_CONNECTED){
    
    Serial.println("\nConnecting");
    while (WiFi.status() != WL_CONNECTED){
      Serial.print(".");
      delay(500);
      dcnt++;
      if (dcnt % 30 == 0){
        dcnt = 0;
        Serial.println("");
      }
          
    }
    Serial.print("ESP32 IP: ");
    Serial.println(WiFi.localIP());
    server.begin();
  }
    
}

#endif

void setup() {
  // configure PIN mode
  pinMode(SPI_CS1, OUTPUT);
  pinMode(SPI_CS2, OUTPUT);
  pinMode(SPI_CS3, OUTPUT);
  pinMode(SPI_CS4, OUTPUT);

  digitalWrite(SPI_CS1, HIGH);
  digitalWrite(SPI_CS2, HIGH);
  digitalWrite(SPI_CS3, HIGH);
  digitalWrite(SPI_CS4, HIGH);

  // initialize SPI interface for MCP3208
  SPISettings settings(ADC_CLK, MSBFIRST, SPI_MODE0);
  spi1.begin(SPI_CLK1, SPI_MISO1, SPI_MOSI1, SPI_CS1);
  spi1.beginTransaction(settings);

  // We will use serial communications in any case. 
  // In WiFi, just jo get the IP number in the local network
  Serial.begin(115200);  

#ifdef _USE_SERIAL_
  // initialize serial
  espdaq.comm(&Serial);
#endif

#ifdef _USE_WIFI_
  Serial.println("Attempting to connect");
   WiFi.begin(ssid, password);
  connect_wifi_ap();
  espdaq.comm(0);
#endif


}



void loop() {

#ifdef _USE_WIFI_
  // Check if we still have wifi connection to the access point
  connect_wifi_ap();
  WiFiClient client = server.available();
  delay(100);
  if (client){
    client.setTimeout(1);
    Serial.println("Client connected!");
    espdaq.comm(&client);
    while (client.connected()){
      espdaq.repl();
    }
  }
  
#else
  
  // Parse Command
  espdaq.repl();
#endif

  return;

}

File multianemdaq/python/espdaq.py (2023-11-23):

# -*- coding: utf-8 -*-

import serial
import time
import numpy as np
import threading
import argparse

from xmlrpc.server import SimpleXMLRPCServer



class ESPDaq(object):

    def __init__(self, dev='/dev/ttyUSB0', speed=115200):
        
        self.s = serial.Serial(dev, speed, timeout=100)
        self.dev = dev
        self.speed = speed
        self.avg(100)
        self.period(100)
        self.fps(1)
        self.frames = []
        self.thrd = None
        self.acquiring = False
        self.nread = 0
        self.stopaq = False
    def close(self):
        self.s.close()
        return None
    def open():
        if self.s.is_open:
            self.s.close()
        self.s.open()
        return None
    def avg(self, val=None):
        if val is None:
            cmd = '?A\n'.encode('ascii')
            self.s.write(cmd)
            b = self.s.readline()
            self._avg = int(b)
            return self._avg
        else:
            if val < 1 or val > 1000:
                val = 1
            val = int(val)
            self._avg = val
            cmd = '.A{}\n'.format(val).encode('ascii')
            self.s.write(cmd)
            return self.s.readline().decode('ascii')
    def period(self, val=None):
        if val is None:
            cmd = '?P\n'.encode('ascii')
            self.s.write(cmd)
            b = self.s.readline()
            self._period = int(b)
            return self._period
        else:
            if val < 10 or val > 1000:
                val = 100
            val = int(val)
            self._period = val
            cmd = '.P{}\n'.format(val).encode('ascii')
            self.s.write(cmd)
            return self.s.readline().decode('ascii')
    def fps(self, val=None):
        if val is None:
            cmd = '?F\n'.encode('ascii')
            self.s.write(cmd)
            b = self.s.readline()
            self._fps = int(b)
            return self._fps
        else:
            if val < 1 or val > 60000:
                val = 1
            val = int(val)
            self._fps = val
            cmd = '.F{}\n'.format(val).encode('ascii')
            self.s.write(cmd)
            return self.s.readline().decode('ascii')
     
    def stop(self):
        self.stopaq = True
        return
    
    def scan_raw(self):
        self.s.flush()
        nframes = self.fps()

        self.frames = []
        self.nread = 0
        self.s.write(b'*\n')
        time.sleep(0.05)
        self.stopaq = False
        for i in range(nframes):
            self.frames.append(self.s.read(80))
            self.nread += 1
            if self.stopaq:
                self.s.write(b"!")
                time.sleep(0.1)
                self.s.readline() # STOP
                self.s.readline() # i
                time.sleep(1)
                self.s.flush()
                self.s.close()
                self.s = serial.Serial(self.dev, self.speed, timeout=100)
                self.s.flush()
                break
        return self.frames

    def start(self):
        if self.acquiring:
            raise RuntimeError("Illegal operation: System is already acquiring!")
        self.thrd = EspMcpThread(self)
        self.thrd.start()
        self.acquiring = True
    def acquire_raw(self):
        self.scan_raw(self)
        return self.frames
    def read_raw(self):
        if self.thrd is not None:
            self.thrd.join()
            self.thrd = None
            self.acquiring = False
        return self.frames
            
    def isacquiring(self):
        return self.acquiring
    def samplesread(self):
        return self.nread
    
            
    def decode_frame(self, frame):
        h = np.frombuffer(frame, np.uint32, 1, 0)[0]
        t = np.frombuffer(frame, np.uint32, 1, 4)[0]
        num = np.frombuffer(frame, np.uint32, 1, 8)[0]
        E = np.frombuffer(frame, np.uint16, 32, 12)
        f = np.frombuffer(frame, np.uint32, 1, 76)[0]
        return E, t, num, h, f
    def scan(self):

        x = self.scan_raw()

        dados = [self.decode_frame(y) for y in x]
        nfr = len(x)

        E = np.zeros((nfr, 32), np.uint16)

        t0 = dados[0][1]
        if nfr == 1:
            freq = 1000/self._period
        else:
            dt = 0
            for i in range(1,nfr):
                dt = dt + (dados[i][1]-dados[i-1][1])
            dtm  = dt / (nfr-1)
            freq = 1000/dtm
            
        for i in range(nfr):    
            E[i,:] = dados[i][0]
        return E, freq
    def scanbin(self):
        E, f = self.scan()
        
        return E.tobytes(), int(E.shape[0]), int(E.shape[1]), float(f)
    def status(self):
        return "OK"
    def reopen(self):
        self.s.close()
        time.sleep(1)
        self.s = serial.Serial(self.dev, self.speed, timeout=100)
        return "OK"
    
    
        
class EspMcpThread(threading.Thread):
    def __init__(self, dev):
        threading.Thread.__init__(self)
        self.dev = dev
        return
    def run(self):
        self.dev.scan_raw()
    
        
        
def start_server(ip='localhost', port=9523, comport='/dev/ttyUSB0', baud=115200):
    dev = ESPDaq(comport, baud)
    print("Starting XML-RPC server")
    print("IP: {}, port: {}".format(ip, port))
    server = SimpleXMLRPCServer((ip, port), allow_none=True)
    server.register_instance(dev)
    server.serve_forever()


if __name__ == "__main__":
    print("Creating interface ...")
    parser = argparse.ArgumentParser(description="ESPDaq server")
    parser.add_argument("-i", "--ip", help="IP address of the XML-RPC server", default="localhost")
    parser.add_argument("-p", "--port", help="XML-RPC server port", default=9523, type=int)
    parser.add_argument("-s", "--comport", help="Serial port to be used", default="/dev/ttyUSB0")

    args = parser.parse_args()
    start_server(args.ip, args.port, args.comport)
    

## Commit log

2021-04-16 Initial commit for the multianem project
    [cta.kicad_pcb, cta.sch, fundo.scad]
2021-04-16 Added other boards to the project.
    I think they will be useful in the future. For now I will just keep them here.
    [cta.kicad_pcb, cta.sch]
2021-04-16 Working on making the multinanem16 board use symmetric power input.
    This way I can use more types of op-amps.
    [cta.kicad_pcb, cta.sch]
2021-04-18 Got arduino to read 32 channels!
    Still need to develop an interface. I think I will use the Scanivalve as a template.
2021-04-19 Added more power inputs to the board
    To make it easy to stack the 8 channel boards, added a Vcc and GND inputs.
    [cta.kicad_pcb, cta.sch]
2021-04-20 Working on adding symmetric power to the multianem16 board.
    Almost done.
    [cta.kicad_pcb, cta.sch]
2021-04-23 Finnished adding Vee to the 16 anemometers board.
    [cta.kicad_pcb, cta.sch]
2021-04-23 Improved the multianem16 board
    Moved the power terminal block to the other side of the board.
    [cta.kicad_pcb]
2021-04-25 Working on new circuit
    Changed TerminalBlock footprint to pin header for thermistor probe.
    [cta.kicad_pcb, cta.sch]
2021-04-25 Setting up the the board for the on circuit.
    Depending on the offset of the opamp, the circuit will need some help turning on. Getting ready to implement this.
    [cta.kicad_pcb]
2021-04-29 The multianem16 board is almost ready: need to replace Ron by an diode
    The problem is that with a resistor every single anemometer is coupled to the others. A diode (1n4148) should isolate them.
    The board that I built was kind of poor. Too many flaws in the traces.
    [cta.kicad_pcb, cta.sch]
2021-05-01 Replaced the Ron? resistors by Don? capacitors
    I tested the original board and it appeared to be working. Let's try this for real!
    [cta.kicad_pcb, cta.sch]
2021-05-05 Worked on data acquisition using tghe usb port
    For now a very simple interface is employed. I also wrote a python interface to the board.
    Now I will have to write a XML-RPC server so that the computer can aquire the data. The esp32 will be connected to a raspberry pi and from there through a cabled network to the computer.
2021-05-06 Small mistake that had problems compiling depending on arduino version
    char* -> uint8_t*
    [multianemdaq.ino]
2021-05-20 Started working on 8 anemometer board
    The 16 anemometer board is working. But I think that 16 is too much. It would be better to use 8 anemometers per board.
    The experience in building and using the multianem16 board and the esp32-daq-board showed some flaws in the design. Not related to the electronic circuit.
    The following problems were observed:
    * Large current. For 32 anemometers, more than 3 A was observed. With a board with 8 anemometers, a current of 1 A per board would be sufficient.
    * More flexible usage.
    * Need to design a multi-temperature board.
    * Sharing the ground between different boards was clumsy. This problem was more noticeable in the daq board. In the new design, t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
    [cta.kicad_pcb, cta.sch]
2021-05-20 Created the multiname8 board
    I recycled the multinam16 board and the numbering of each anemometer's component is 1-4 and 9-12. I might (might...) change the numbering 9-12 to 5-8. The output is also inverted inthe flat cable coming out of the board.
    [cta.kicad_pcb, cta.sch]
2021-06-04 Major changes in the esp daq board.
    Now the analog ground is given in a ninth wire for each board in the same flat cable.
    Power supply will be from the ESP board.
    [cta.kicad_pcb, cta.sch]
2021-06-05 Added a terminal block to esp32-daq-board
    This terminal exposes the 5V supply, reference voltage and ground. This makes it easier to adjust the the reference voltage.
    [cta.kicad_pcb, cta.sch]
2021-06-05 Moved the box to the corresponding printer3d folder
    [fundo.scad]
2021-06-05 Created 3d printed parts for the box
    For now only the bottom plates and lateral plates where BNC connectors go has been drawn.
    [fundo.scad, lateral.scad]
2021-06-16 Created gerber files for fabrication
    I will try to build the board on some fab.
    [cantoneira.scad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]
2021-06-16 Unifying all the grounds AGND and DGND
    On the previous version, each anemometer had a ground that was connected to the AGND present in the MCP3208. This was burning the MCP3208. I still need to undersant how to work with this AGND properly.
    [cta.kicad_pcb, cta.sch]
2021-06-20 Fixing a few things on the python daq code
    [espdaq.py, espdaqclient.py]
2021-06-29 Gerber files for multianem8 and started working on ctaflex
    Sent the gerber files to JLCPCB to manufacture the multianem8 boards.
    Started working on ctaflex, a single anemometer circuit very flexible for testing different types of thermistors and allowing the accurate measurement of resistance.
    [cta-B_Cu.gbl, cta-B_Mask.gbs, cta-B_Paste.gbp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]
2022-06-01 Added numbers to the lateral pannels
    Now we one pannel for the right hand side (1-4) and one for the left (5-8).
    [lateral-01_04.scad, lateral-05_08.scad]
2023-04-10 Simplified programming a little bit
    Now there is a very long timeout. Things appear to be working but it is not very accepting of errors.
    [espdaq.py, multianemdaq.ino]
2023-04-23 Created module hotwire.py
    This module deals with calculating velocities and handling anemometer
    calibration.
    The notebook `hotwire-example.ipynb` has a simple example using the module.
